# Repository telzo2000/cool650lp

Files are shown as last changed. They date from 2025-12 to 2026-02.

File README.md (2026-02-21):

# cool650lp

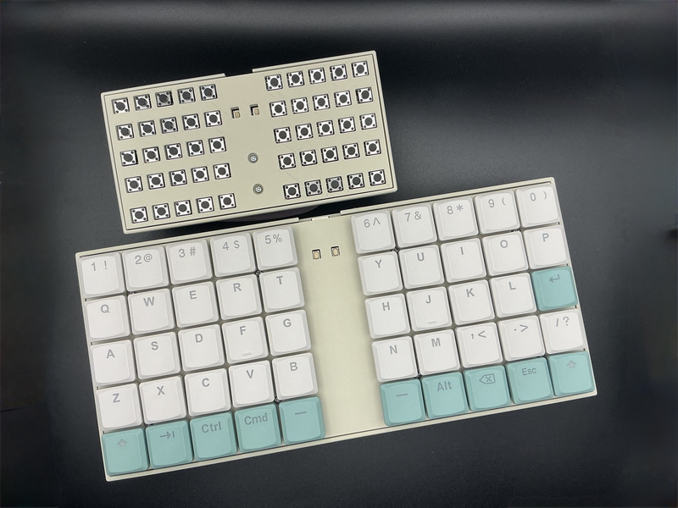
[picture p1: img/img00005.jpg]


## What is cool650lp?

cool650lp is 50% keyboard.
<br>
cool650lp use Low profile keyswitches and keycaps.
<br>
cool650lp use seeed RP2040-Zero,run qmk_firmware.
<br>
<br>

## firmware

cool650lp change keymap by [vial](https://vial.rocks/).

<br>

<br>

## buildguide

https://github.com/telzo2000/cool650lp/blob/main/buildguide_for_cool650lp.md

<b>Main steps</b>

1 Soldering switchsocket.
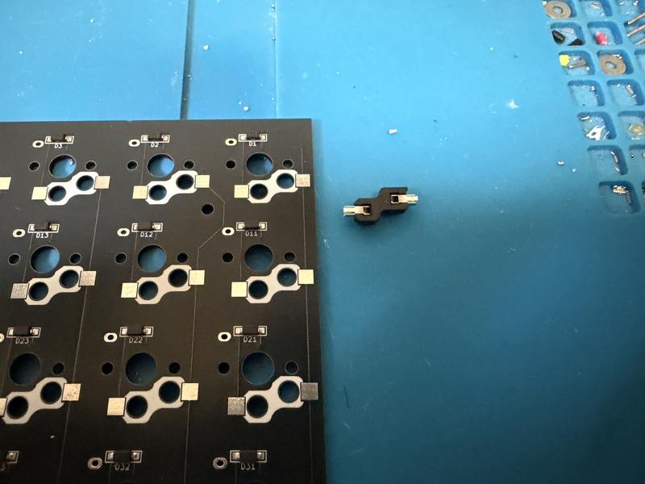
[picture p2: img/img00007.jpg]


[Switch socketハンダ付け動画](https://youtu.be/ZnbgaueMR4w?si=_JLjD--3HJJ5Pu7Q)

<br>

2 Soldering RP2040-Zero.
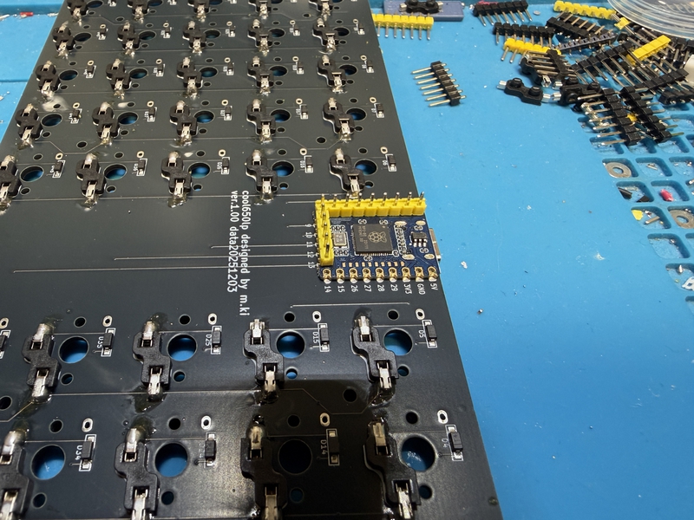
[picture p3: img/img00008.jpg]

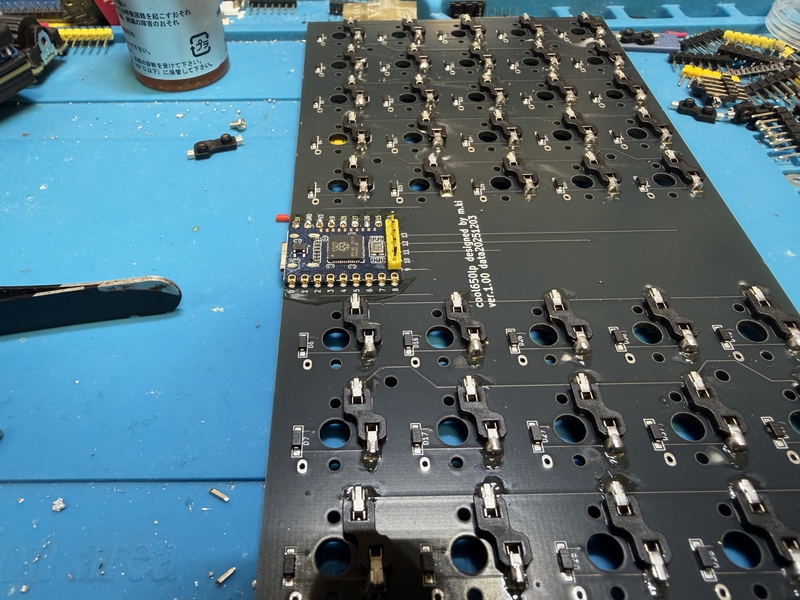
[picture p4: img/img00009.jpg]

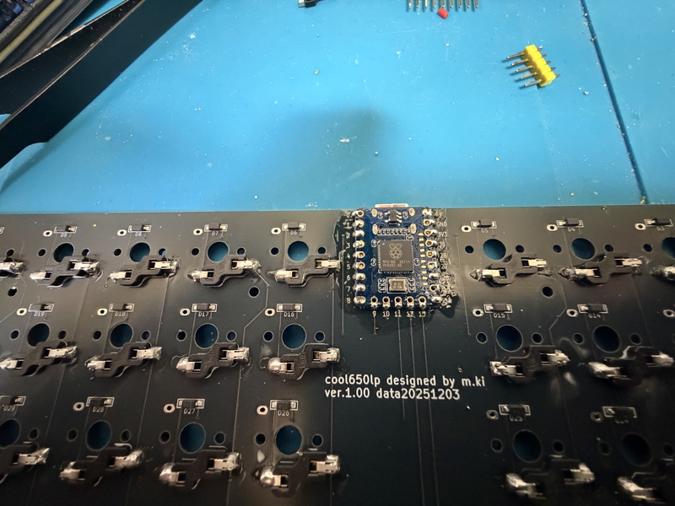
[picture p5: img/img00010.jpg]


[RP2040-Zeroのハンダ付け動画](https://youtu.be/FV4INvCWlU0)
<br>

3 Insert the switch socket into the top plate and then the PCB.

4 Insert the bottom case.

5 Insert the screw from above and secure it with the nut on the bottom case side.

6 Connect to your PC with a USB cable and install the firmware by dragging and dropping.

<br>

## BOM

<b>common parts</b>
| No. | Patrs | Quantity | remarks | Suppliers | Cost |
|--|--|--|--|--|--|
|番号|名前|数|備考|調達先|参考価格（送料込）|<br>
|1|PCB|1||[JLCPCB](https://jlcpcb.com)||<br>
|2|Top plate|2|3D Print|||
|3|Bottom case|2|3D Print|||
|4|Diode<br>ダイオード|50|SMD、PCBA済み|[遊舎工房](https://yushakobo.jp)<br>[Talp Keyboard](https://talpkeyboard.net)<br>[Daily Craft Keyboard](https://shop.dailycraft.jp)等|100個で220円程度から|
|5|Swith socket<br>スイッチソケット|50|choc|[遊舎工房](https://yushakobo.jp)<br>[Talp Keyboard](https://talpkeyboard.net)<br>[Daily Craft Keyboard](https://shop.dailycraft.jp)等|10個で165円程度|
|6|RP2040-Zero|1|MCU Board|[Talp keyboard](https://shop.talpkeyboard.com/products/rp2040-zero-usb-c-compatible)[Waveshare](https://www.waveshare.com/rp2040-zero.htm)|400円ぐらい|
|7|Screw<br>ネジ|8|スリムヘッドM2 6mm|[遊舎工房](https://shop.yushakobo.jp/products/a0800s2?variant=37665432535201)|50本880円(遊舎工房)|
|8|Nut<br>ナット|8|M2ネジに付属していることが多い|DIY shop||
|9|Keycap<br>キーキャップ|50|ロープロが最適|[遊舎工房](https://yushakobo.jp)<br>[Talp Keyboard](https://talpkeyboard.net)<br>[Daily Craft Keyboard](https://shop.dailycraft.jp)||

<br>

In addition, USB cable, etc. are required.
<br>
この他に、USBケーブル等が必要です。
<br>

<br>

# license

[CC BY-NC-SA](https://creativecommons.org/licenses/by-nc-sa/4.0/deed.ja)



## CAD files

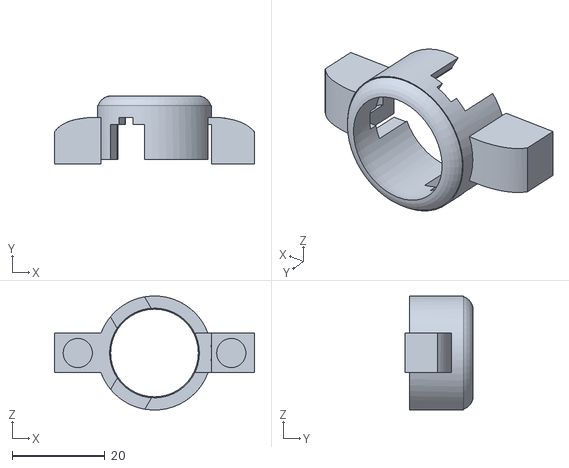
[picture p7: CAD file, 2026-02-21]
case_design/cool650lp_tb/cool650lp_tb_knob_b.stl
43.0 x 14.7 x 24.5

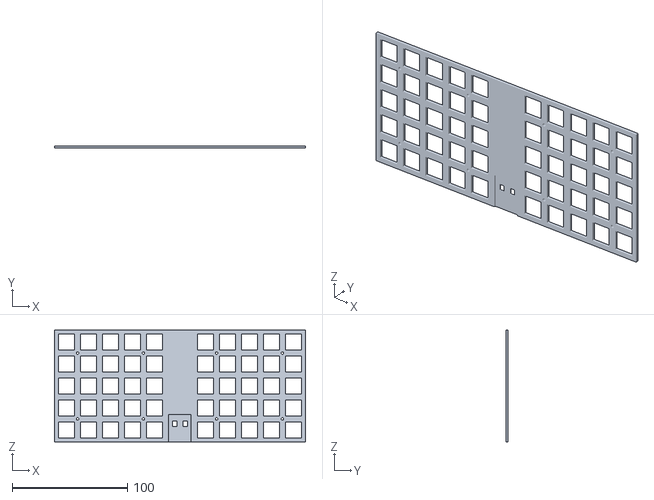
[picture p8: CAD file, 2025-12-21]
case_design/cool650lp_topplate.stl
217.9 x 2.00 x 97.2

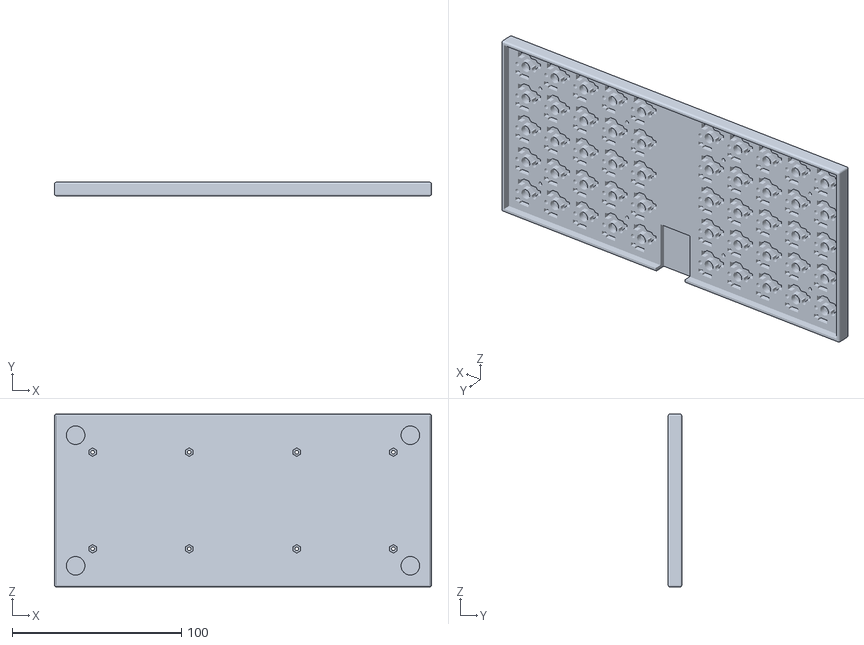
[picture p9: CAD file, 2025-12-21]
case_design/cool650lp_bottomcase.stl
222.9 x 8.00 x 102.2

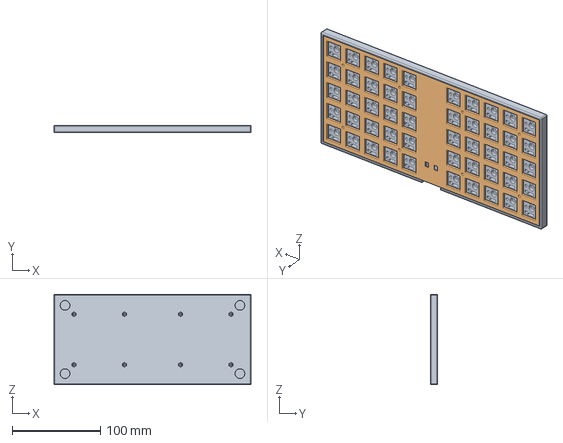
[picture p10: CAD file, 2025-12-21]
case_design/cool650lp_case_design v3.step
222.9 x 8.00 x 102.2 mm

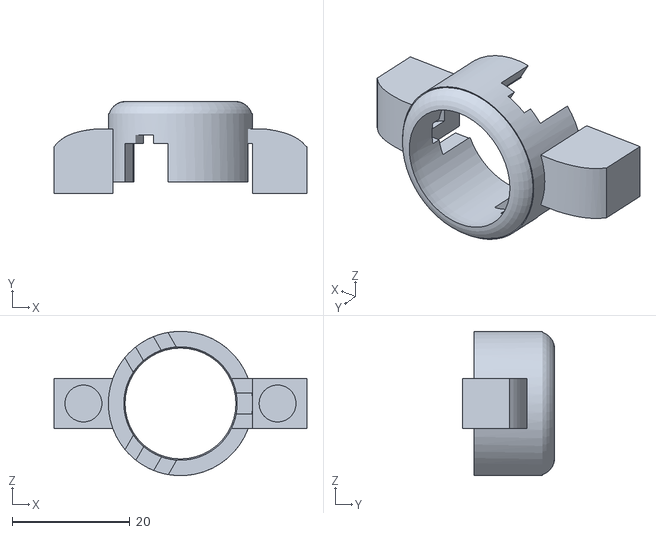
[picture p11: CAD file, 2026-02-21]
case_design/cool650lp_tb/cool650lp_tb_trackball_top.stl
43.0 x 15.7 x 24.5

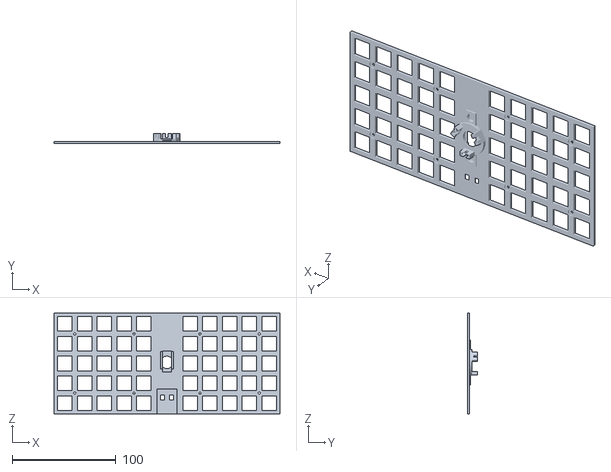
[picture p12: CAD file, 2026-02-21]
case_design/cool650lp_tb/cool650lp_tb_topplate_type_A.stl
217.9 x 10.0 x 97.2

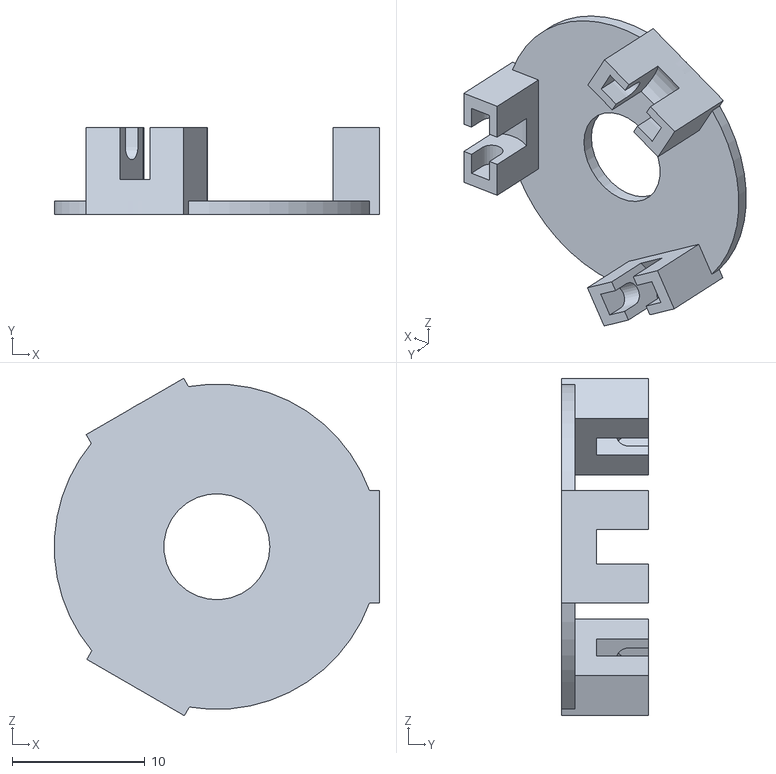
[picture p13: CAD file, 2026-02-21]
case_design/cool650lp_tb/cool650lp_tb_trackballunit_bottom.stl
24.5 x 6.54 x 25.5

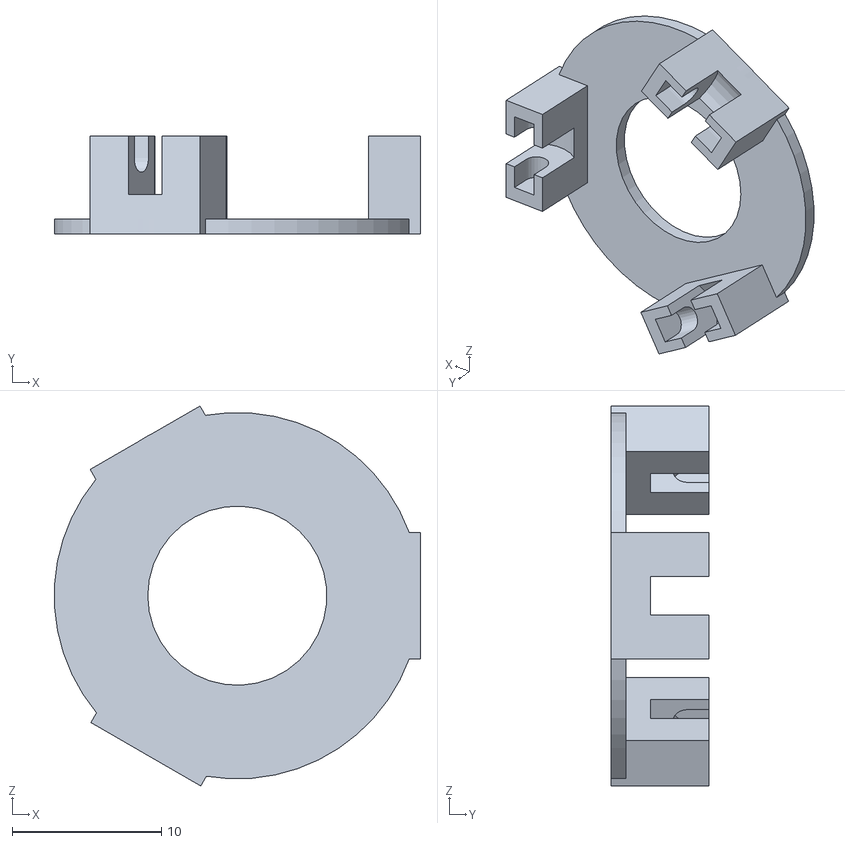
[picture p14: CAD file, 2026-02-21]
case_design/cool650lp_tb/cool650lp_tb_trackball_bottom.stl
24.5 x 6.54 x 25.5

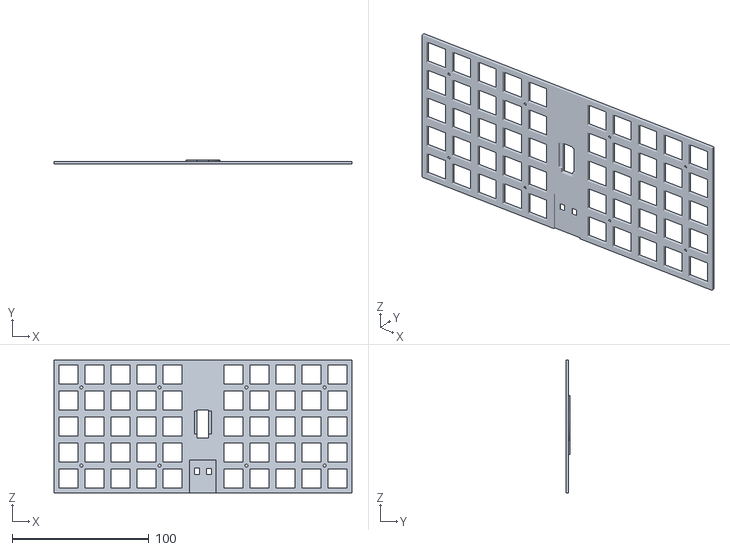
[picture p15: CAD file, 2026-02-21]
case_design/cool650lp_tb/cool650lp_tb_topplate.stl
217.9 x 3.00 x 97.2

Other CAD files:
case_design/cool650lp_tb/cool650lp_tb_trackballunit_top.stl
case_design/cool650lp_tb/cool650lp_case_design v7_.3mf
case_design/cool650lp_tb/cool650lp_tb_bottomcase.stl
case_design/cool650lp_tb/cool650lp_case_design v7.stl
case_design/cool650lp_tb/cool650lp_case_design v7_.stl

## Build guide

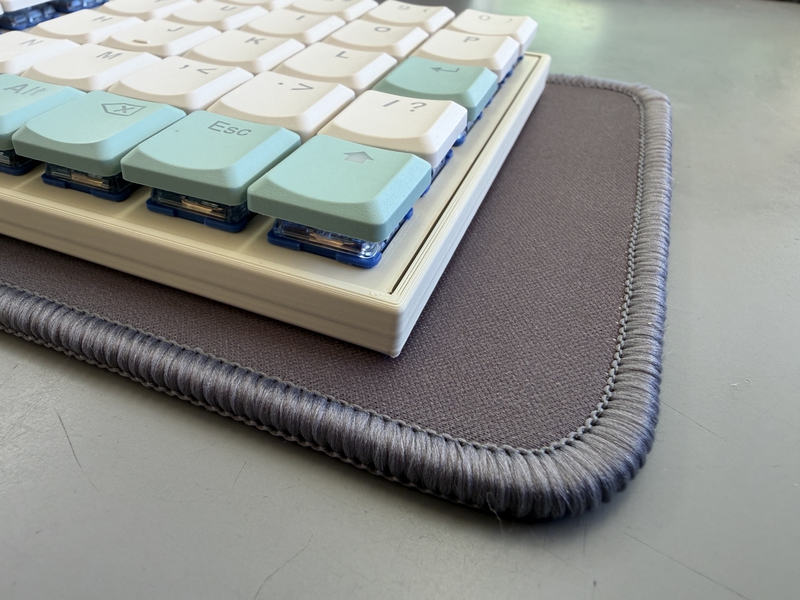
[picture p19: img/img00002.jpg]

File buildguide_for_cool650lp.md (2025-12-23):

 　# Buildguide for cool650lp
<br>

## 0 部品の確認
<br>
Follow the BOM on github's readme.md to make sure that all the parts are available.
<br>
githubのreadme.mdのBOMに沿って、部品が全て揃っているかを確認してください。
<br>

## 1 ダイオードのはんだ付け

If the diode is already soldered, please skip this operation.
<br>
すでにダイオードのはんだ付けされている場合は、この作業を省略してください。
<br>
<br>
This work is done on the left and right keyboard boards respectively.
<br>
この作業は左右のキーボード基板でそれぞれ行います。
<br> 
Solder the diodes to the back of PCB.
<br>
PCBの裏面にダイオードのハンダ付けをします。
<br>
As expected, it is compatible with SMD type.
<br>
ダイオードは、SMDタイプに対応しています。
<br>
Diodes have polarity, so be careful about the direction in which they are installed.
<br>
ダイオードには極性がありますので、取り付ける向きに注意してください。
<br>

[ダイオード（SMD)のはんだ付けの動画](https://youtu.be/ODk16bd4XkA)
<br>

<br>

## 2  スイッチソケットのハンダ付け

cool650lp supports choc switch sockets.
<br>
cool650lpでは、chocのスイッチソケットに対応しています。
<br><br>
Solder the switch socket to the back of the keyboard board.
<br>
キーボード基板の裏面にスイッチソケットのハンダ付けをします。
<br>

[Switch socketハンダ付け動画](https://youtu.be/ZnbgaueMR4w?si=_JLjD--3HJJ5Pu7Q)

<br>

## 3 RP2040-Zeroのハンダ付け

<br>
次の動画を参考にしてハンダ付けをしてください。
<br>

[RP2040-Zeroのはんだ付け動画](https://youtu.be/FV4INvCWlU0?si=ENKXU5vA0EeIhCRw)

## 4　キースイッチの装着

Insert the key switch in the following order: top case, then PCB.
<br>
トップケース、PCBの順になるように、キースイッチを差し込んでください。
<br>
When inserting the key switch, make sure the pins are straight.
<br>
キースイッチを差し込む時、キースイッチのピンが真っ直ぐになっているか、確認してください。
<br>

## 5 ボトムケースの装着

Attach the bottom case to the underside of the PCB, with the bumpy side of the bottom case facing the PCB.
<br>
PCBの下面にボトムケースを装着します。ボトムケースには凹凸がある面が、PCBに向くようにしてください。
<br>
<br>
Insert eight 6mm M2 screws into the top case. Secure the bottom case with M2 nuts.
<br>
トップケース側から、M2ネジ6mmを８箇所差し込みます。ボトムケース側では、M2ナットで固定してください。
<br>
<br>

##  6　キーキャップの装着

Please attach your favorite keycap.
<br>
お好きなキーキャップを装着してください。
<br>

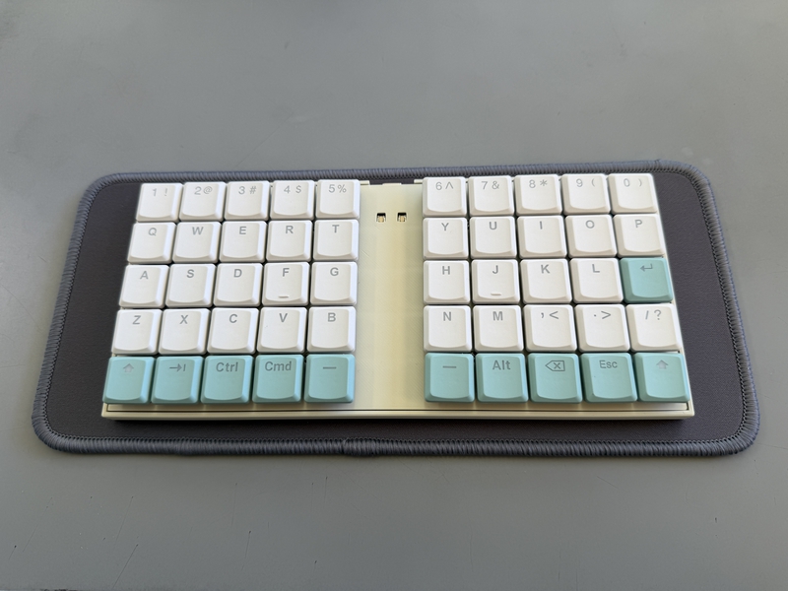
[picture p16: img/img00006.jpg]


## 7 動作確認について

Connect the keyboard to your PC with a USB cable, then press the reset button and boot button on the RP2040-Zero through the rectangular window in the top case.
<br>
PCとキーボードをUSBケーブルで繋ぎます。その後、トップケースにに開いた四角窓から、RP2040-Zeroのリセットボタン、ブートボタンを押します。
<br>
<br>

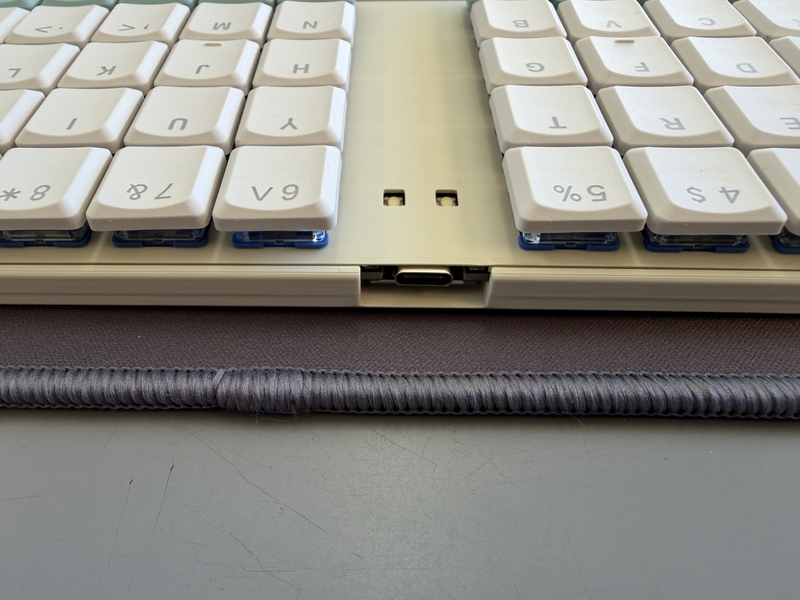
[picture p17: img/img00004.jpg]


Press and hold the left button and then press the right button to mount a folder on your PC.
<br>
ボタンは、左を押したまま、右を押すと、PCにフォルダがマウントされます。
<br>
<br>

Just drag and drop the uf2 file from [here](https://github.com/telzo2000/cool650lp/tree/main/firmware) into the mounted folder.
<br>

[ここ](https://github.com/telzo2000/cool650lp/tree/main/firmware)にあるuf2ファイルを、マウントされたフォルダにドラッグ&ドロップすれば大丈夫です。
<br>
<br>

## 8 完成

After attaching non-slip rubber to the bottom of the bottom case, it's done.
<br>

ボトムケースの底面に、滑り止めゴムを取り付けたら、完成です。
<br>
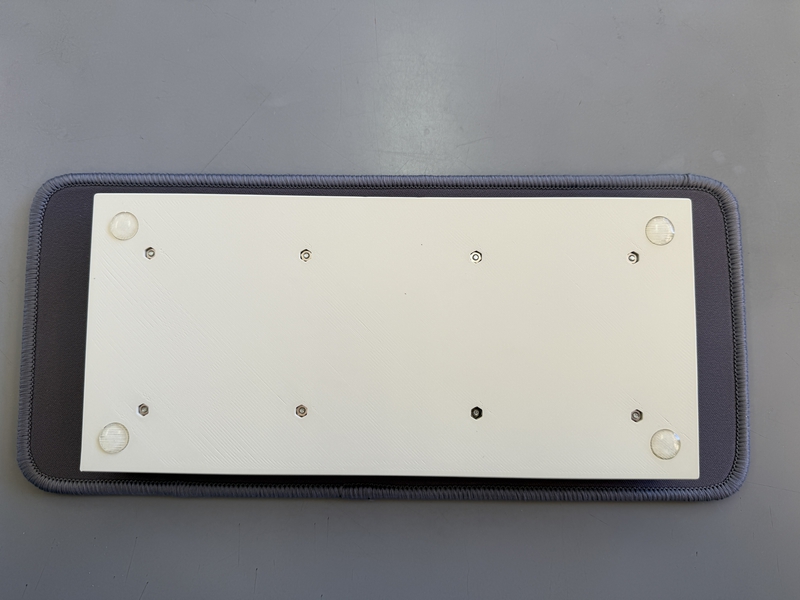
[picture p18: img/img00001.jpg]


Please enjoy a life with a better keyboard.
<br>
よりよいキーボードのある生活を楽しんでください。
<br>
